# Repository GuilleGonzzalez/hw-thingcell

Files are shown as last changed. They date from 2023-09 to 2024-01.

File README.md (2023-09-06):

# ThingCell



## Description
'ThhingCell' is a device designed to control a other devices with a relay with MQTT over 4G .

Firmware used in this device is [fw-thingcell](https://github.com/GuilleGonzzalez/fw-thigcell), a custom made firmware implemented using [Arduino Home Assistant](https://github.com/dawidchyrzynski/arduino-home-assistant/tree/main) Arduino library ([docs](https://dawidchyrzynski.github.io/arduino-home-assistant/)).

## Power supply (WIP)

## Microprocessor (WIP)
Espressif [ESP8266](https://www.espressif.com/en/products/modules) module.

## Environmental sensing (WIP)
The board has enviromental sensors to measure temperature, humidity and atmospheric pressure:

### Temperature and humidity sensor
* Sensirion [SHT40](https://sensirion.com/products/catalog/SHT40).

### Pressure sensor
* Bosch [BMP581](https://www.bosch-sensortec.com/products/environmental-sensors/pressure-sensors/bmp581/).
  
## LEDs and buttons (WIP)

## Pin assignment (WIP)

| PIN | Func |
| --- | --- |
| GPIOx | F1 |

## Enclosure (WIP)
* Custom made in [Fusion 360](https://www.autodesk.es/products/fusion-360/overview).

# Changelog (WIP)
All notable changes to this project will be documented in this section.

The format is based on [Keep a Changelog](https://keepachangelog.com/en/1.0.0/)

## [unreleased] - 2023-09-06
Unreleased

[Unreleased]: https://github.com/GuilleGonzzalez/hw-thingcell

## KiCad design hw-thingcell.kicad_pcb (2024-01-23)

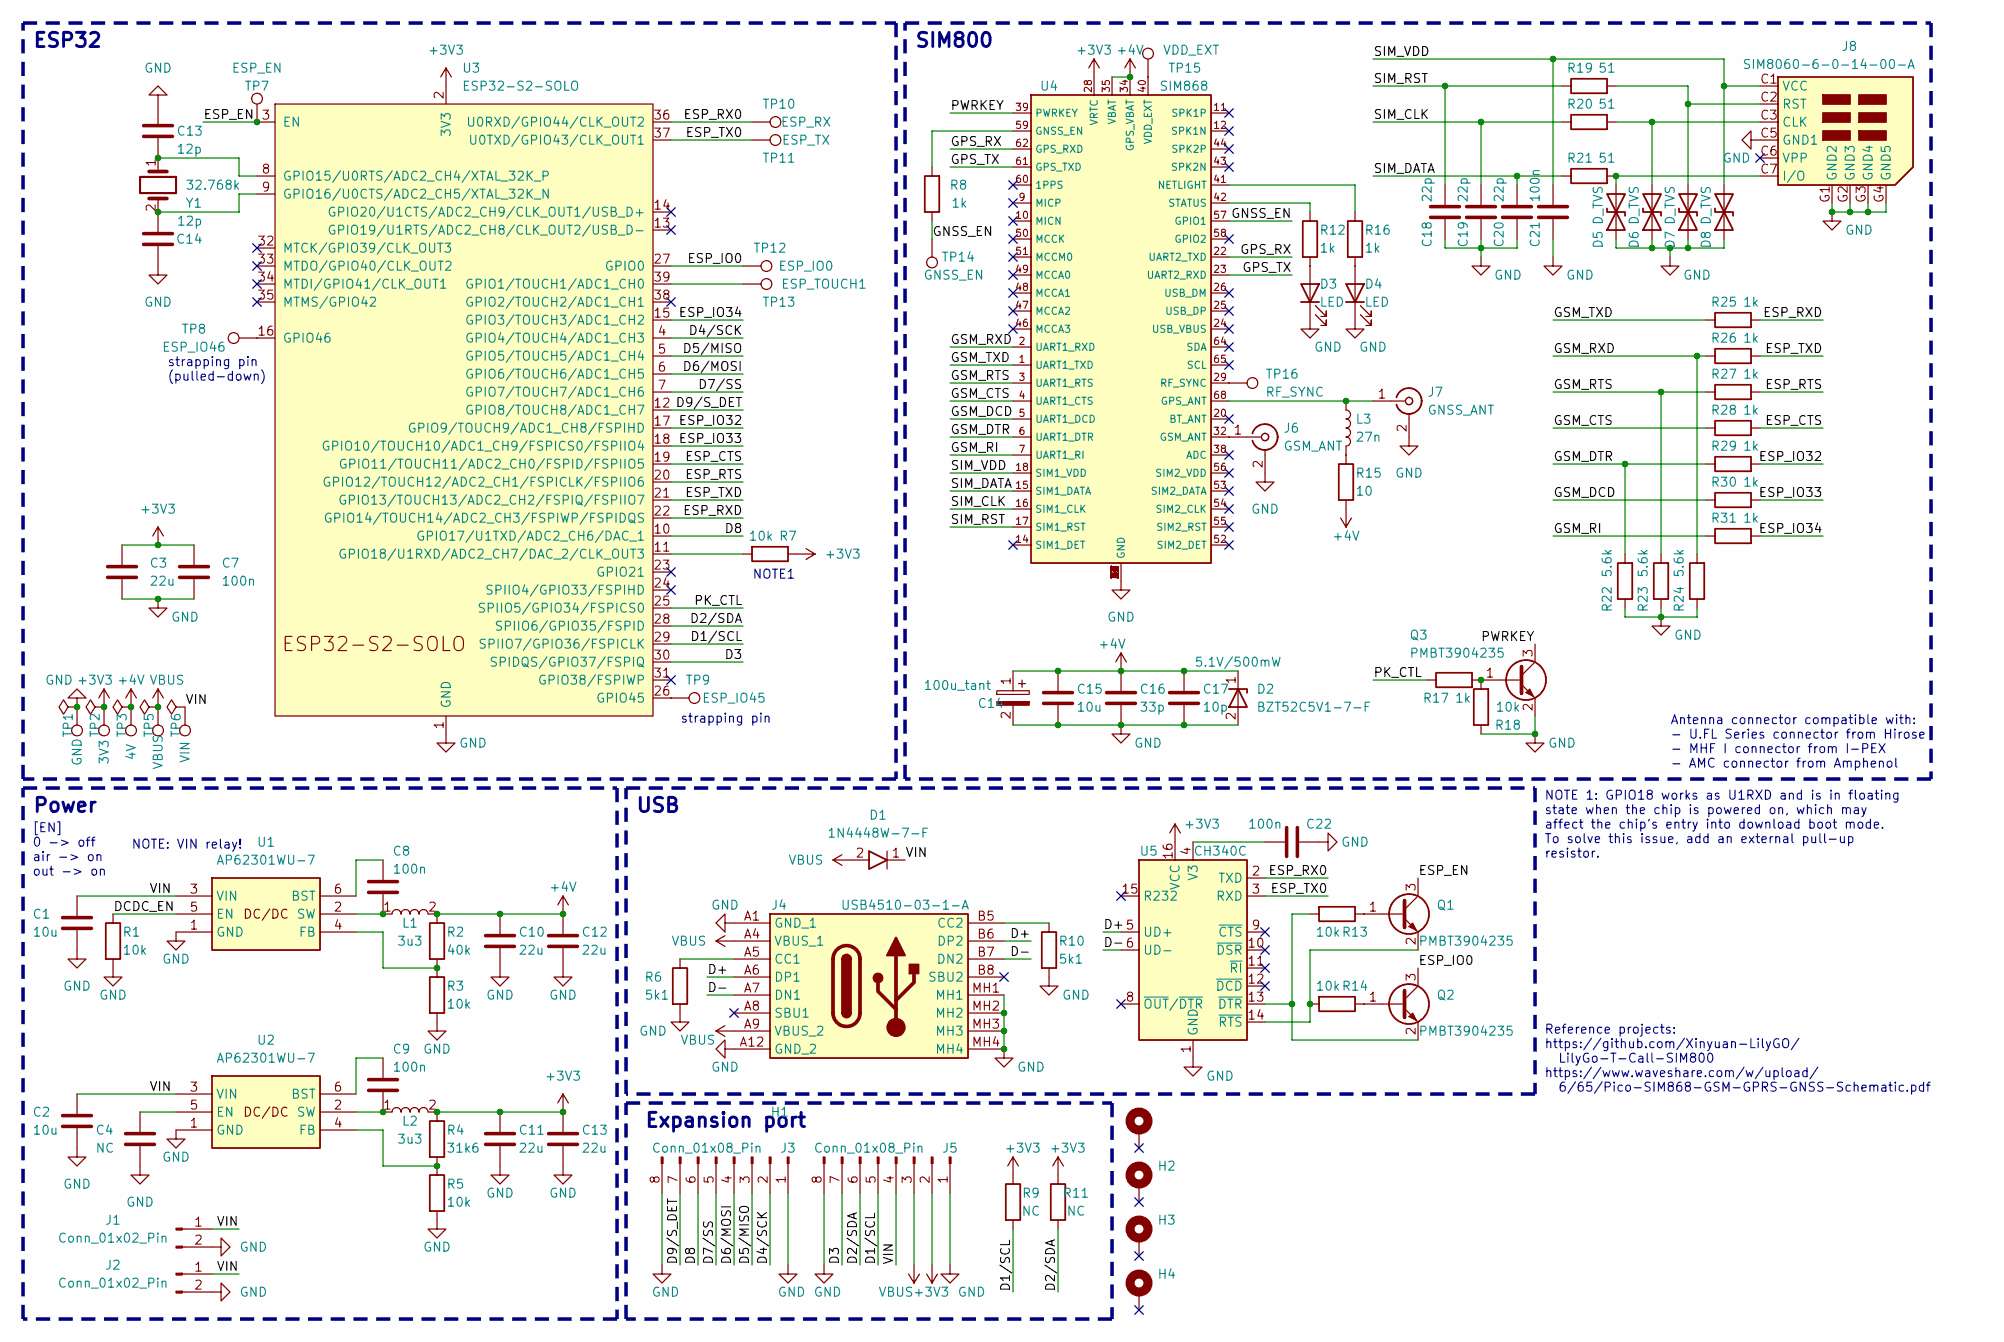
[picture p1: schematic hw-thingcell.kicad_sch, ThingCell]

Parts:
C1, C2, C15: 10u; C_0805_2012Metric
C3, C10, C11, C12, C13: 22u; C_0805_2012Metric
C4: NC; C_0402_1005Metric
C7, C8, C9, C21, C22: 100n; C_0402_1005Metric
C14: 100u_tant; CAPPM3528X210N; Manufacturer_Part_Number TPSB107K006R0250; Mouser Part Number 581-TPSB107K006R0250
C16: 33p; C_0402_1005Metric
C17: 10p; C_0402_1005Metric
C18, C19, C20: 22p; C_0402_1005Metric
D1: 1N4448W-7-F; D_SOD-123; Manufacturer_Part_Number 1N4448W-7-F; Mouser Part Number 621-1N4448W-F
D2: BZT52C5V1-7-F; SOD3716X145N; Manufacturer_Part_Number BZT52C5V1-7-F; Mouser Part Number 621-BZT52C5V1-F
D3, D4: LED; LED_0402_1005Metric
D5, D6, D7, D8: D_TVS; D_0402_1005Metric
H1, H2, H3, H4: MountingHole_Pad; MountingHole_2.2mm_M2_ISO7380_Pad
J1, J2: Conn_01x02_Pin; PinSocket_1x02_P2.54mm_Vertical
J3, J5: Conn_01x08_Pin; PinSocket_1x08_P2.54mm_Vertical
J4: USB4510-03-1-A; USB4510031A; Mouser Part Number 640-USB4510031A
J6: GSM_ANT; U.FL_CONNECTOR
J7: GNSS_ANT; U.FL_CONNECTOR
J8: SIM8060-6-0-14-00-A; SIM8060601400A; Manufacturer_Part_Number SIM8060-6-0-14-00-A; Mouser Part Number 640-SIM8060601400A
L1, L2: 3u3; SRN5020TA3R3M; Manufacturer_Part_Number SRN5020TA-3R3M; Mouser Part Number 652-SRN5020TA-3R3M
L3: 27n; L_0402_1005Metric
Q1, Q2, Q3: PMBT3904235; SOT-23; Manufacturer_PN PMBT3904,235
R1, R3, R5, R7, R13, R14, R18: 10k; R_0402_1005Metric
R2: 40k; R_0402_1005Metric
R4: 31k6; R_0402_1005Metric
R6, R10: 5k1; R_0402_1005Metric
R8, R12, R16, R17, R25, R26, R27, R28, R29, R30, R31: 1k; R_0402_1005Metric
R9, R11: NC; R_0402_1005Metric
R15: 10; R_0402_1005Metric
R19, R20, R21: 51; R_0402_1005Metric
R22, R23, R24: 5.6k; R_0402_1005Metric
TP1: GND; TestPoint_Pad_D1.0mm
TP2: 3V3; TestPoint_Pad_D1.0mm
TP3: 4V; TestPoint_Pad_D1.0mm
TP5: VBUS; TestPoint_Pad_D1.0mm
TP6: VIN; TestPoint_Pad_D1.0mm
TP7: ESP_EN; TestPoint_Pad_D1.0mm
TP8: ESP_IO46; TestPoint_Pad_D1.0mm
TP9: ESP_IO45; TestPoint_Pad_D1.0mm
TP10: ESP_RX; TestPoint_Pad_D1.0mm
TP11: ESP_TX; TestPoint_Pad_D1.0mm
TP12: ESP_IO0; TestPoint_Pad_D1.0mm
TP13: ESP_TOUCH1; TestPoint_Pad_D1.0mm
TP14: GNSS_EN; TestPoint_Pad_D1.0mm
TP15: VDD_EXT; TestPoint_Pad_D1.0mm
TP16: RF_SYNC; TestPoint_Pad_D1.0mm
U1, U2: AP62301WU-7; SOT95P280X100-6N; Manufacturer_Part_Number AP62301WU-7; Mouser Part Number 621-AP62301WU-7
U3: ESP32-S2-SOLO
U4: SIM868
U5: CH340C; SOIC-16_3.9x9.9mm_P1.27mm
Y1: 32.768k; SC32S7PF20PPM; Manufacturer_Part_Number SC32S-7PF20PPM; Mouser Part Number 628-SC32S-7PF20PPM

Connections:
/D1/SCL: J5.5, R9.2, U3.29 (SPIIO7/GPIO36/FSPICLK)
/D2/SDA: J5.6, R11.2, U3.28 (SPIIO6/GPIO35/FSPID)
/D3: J5.7, U3.30 (SPIDQS/GPIO37/FSPIQ)
/D4/SCK: J3.2, U3.4 (GPIO4/TOUCH4/ADC1_CH3)
/D5/MISO: J3.3, U3.5 (GPIO5/TOUCH5/ADC1_CH4)
/D6/MOSI: J3.4, U3.6 (GPIO6/TOUCH6/ADC1_CH5)
/D7/SS: J3.5, U3.7 (GPIO7/TOUCH7/ADC1_CH6)
/D8: J3.6, U3.10 (GPIO17/U1TXD/ADC2_CH6/DAC_1)
/D9/S_DET: J3.7, U3.12 (GPIO8/TOUCH8/ADC1_CH7)
/D+: J4.A6 (DP1), J4.B6 (DP2), U5.5 (UD+)
/D-: J4.A7 (DN1), J4.B7 (DN2), U5.6 (UD-)
/DCDC_EN: R1.1, U1.5 (EN)
/ESP_CTS: R28.2, U3.19 (GPIO11/TOUCH11/ADC2_CH0/FSPID/FSPIIO5)
/ESP_EN: Q1.3, TP7.1, U3.3 (EN)
/ESP_IO0: Q2.3, TP12.1, U3.27 (GPIO0)
/ESP_IO32: R29.2, U3.17 (GPIO9/TOUCH9/ADC1_CH8/FSPIHD)
/ESP_IO33: R30.2, U3.18 (GPIO10/TOUCH10/ADC1_CH9/FSPICS0/FSPIIO4)
/ESP_IO34: R31.2, U3.15 (GPIO3/TOUCH3/ADC1_CH2)
/ESP_RTS: R27.2, U3.20 (GPIO12/TOUCH12/ADC2_CH1/FSPICLK/FSPIIO6)
/ESP_RX0: TP10.1, U3.36 (U0RXD/GPIO44/CLK_OUT2), U5.2 (TXD)
/ESP_RXD: R25.2, U3.22 (GPIO14/TOUCH14/ADC2_CH3/FSPIWP/FSPIDQS)
/ESP_TX0: TP11.1, U3.37 (U0TXD/GPIO43/CLK_OUT1), U5.3 (RXD)
/ESP_TXD: R26.2, U3.21 (GPIO13/TOUCH13/ADC2_CH2/FSPIQ/FSPIIO7)
/GNSS_EN: R8.1, TP14.1, U4.57 (GPIO1)
/GPS_RX: U4.22 (UART2_TXD), U4.62 (GPS_RXD)
/GPS_TX: U4.23 (UART2_RXD), U4.61 (GPS_TXD)
/GSM_CTS: R28.1, U4.4 (UART1_CTS)
/GSM_DCD: R30.1, U4.5 (UART1_DCD)
/GSM_DTR: R22.2, R29.1, U4.6 (UART1_DTR)
/GSM_RI: R31.1, U4.7 (UART1_RI)
/GSM_RTS: R23.2, R27.1, U4.3 (UART1_RTS)
/GSM_RXD: R24.2, R26.1, U4.2 (UART1_RXD)
/GSM_TXD: R25.1, U4.1 (UART1_TXD)
/PK_CTL: R17.1, U3.25 (SPIIO5/GPIO34/FSPICS0)
/PWRKEY: Q3.3, U4.39 (PWRKEY)
/SIM_CLK: C19.1, R20.1, U4.16 (SIM1_CLK)
/SIM_DATA: C20.1, R21.1, U4.15 (SIM1_DATA)
/SIM_RST: C18.1, R19.1, U4.17 (SIM1_RST)
/SIM_VDD: C21.1, D8.2 (A2), J8.C1 (VCC), U4.18 (SIM1_VDD)
/VIN: C1.1, C2.1, D1.1, J1.1, J2.1, J5.4, TP6.1, U1.3 (VIN), U2.3 (VIN)
unnamed: D3.2 (A), R12.2
unnamed: D4.2 (A), R16.2
unnamed: D5.2 (A2), J8.C7 (I/O), R21.2
unnamed: D6.2 (A2), J8.C3 (CLK), R20.2
unnamed: D7.2 (A2), J8.C2 (RST), R19.2
unnamed: J4.A5 (CC1), R6.1
unnamed: J4.B5 (CC2), R10.1
unnamed: J6.1 (In), U4.32 (GSM_ANT)
unnamed: J7.1 (In), L3.1, U4.68 (GPS_ANT)
unnamed: L3.2, R15.1
unnamed: Q1.1, R13.1
unnamed: Q2.1, R14.1
unnamed: Q3.1, R17.2, R18.2
unnamed: C8.1, U1.6 (BST)
unnamed: R2.2, R3.1, U1.4 (FB)
unnamed: C8.2, L1.1, U1.2 (SW)
unnamed: C9.1, U2.6 (BST)
unnamed: C4.1, U2.5 (EN)
unnamed: R4.2, R5.1, U2.4 (FB)
unnamed: C9.2, L2.1, U2.2 (SW)
unnamed: TP13.1, U3.39 (GPIO1/TOUCH1/ADC1_CH0)
unnamed: R7.2, U3.11 (GPIO18/U1RXD/ADC2_CH7/DAC_2/CLK_OUT3)
unnamed: TP9.1, U3.26 (GPIO45)
unnamed: TP8.1, U3.16 (GPIO46)
unnamed: R8.2, U4.59 (GNSS_EN)
unnamed: R16.1, U4.41 (NETLIGHT)
unnamed: TP16.1, U4.29 (RF_SYNC)
unnamed: R12.1, U4.42 (STATUS)
unnamed: TP15.1, U4.40 (VDD_EXT)
unnamed: C22.1, U5.4 (V3)
unnamed: Q2.2, R13.2, U5.13 (~DTR)
unnamed: Q1.2, R14.2, U5.14 (~RTS)
VBUS: D1.2, J4.A4 (VBUS_1), J4.A9 (VBUS_2), J5.3, TP5.1

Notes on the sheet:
NOTE 1: GPIO18 works as U1RXD and is in floating state when the chip is powered on, which may affect the chip’s entry into download boot mode. To solve this issue, add an external pull-up resistor.
NOTE1
strapping pin (pulled-down)
strapping pin
Antenna connector compatible with: - U.FL Series connector from Hirose - MHF I connector from I-PEX - AMC connector from Amphenol
ESP32
[EN] 0 -> off air -> on out -> on
Reference projects: https://github.com/Xinyuan-LilyGO/ LilyGo-T-Call-SIM800 https://www.waveshare.com/w/upload/ 6/65/Pico-SIM868-GSM-GPRS-GNSS-Schematic.pdf
NOTE: VIN relay!
Expansion port
SIM800
Power
USB

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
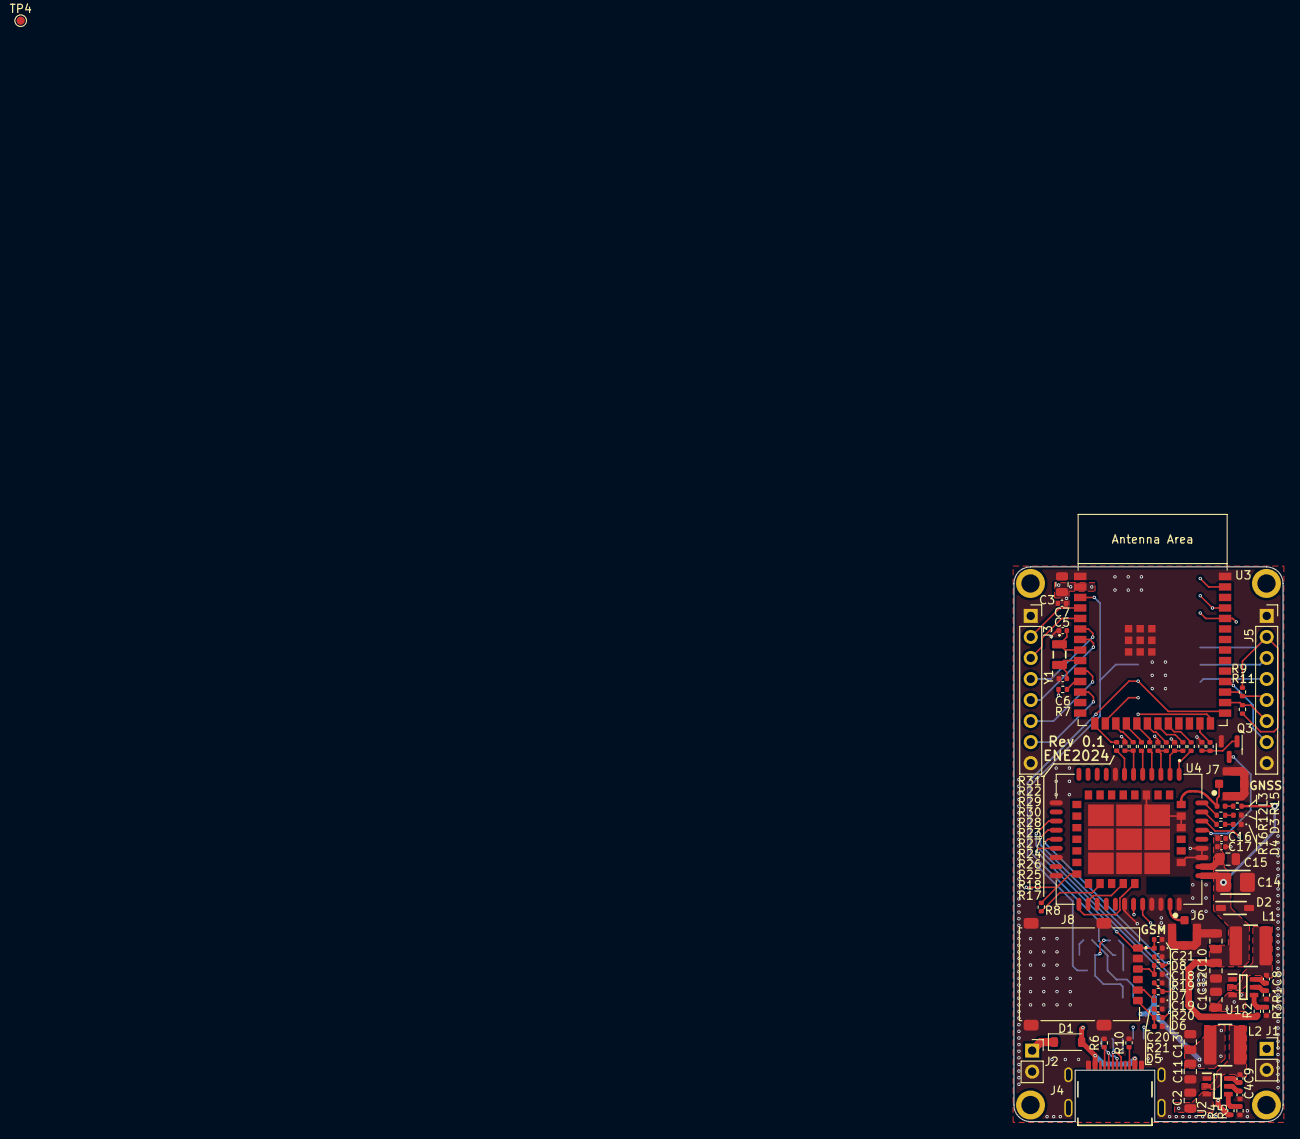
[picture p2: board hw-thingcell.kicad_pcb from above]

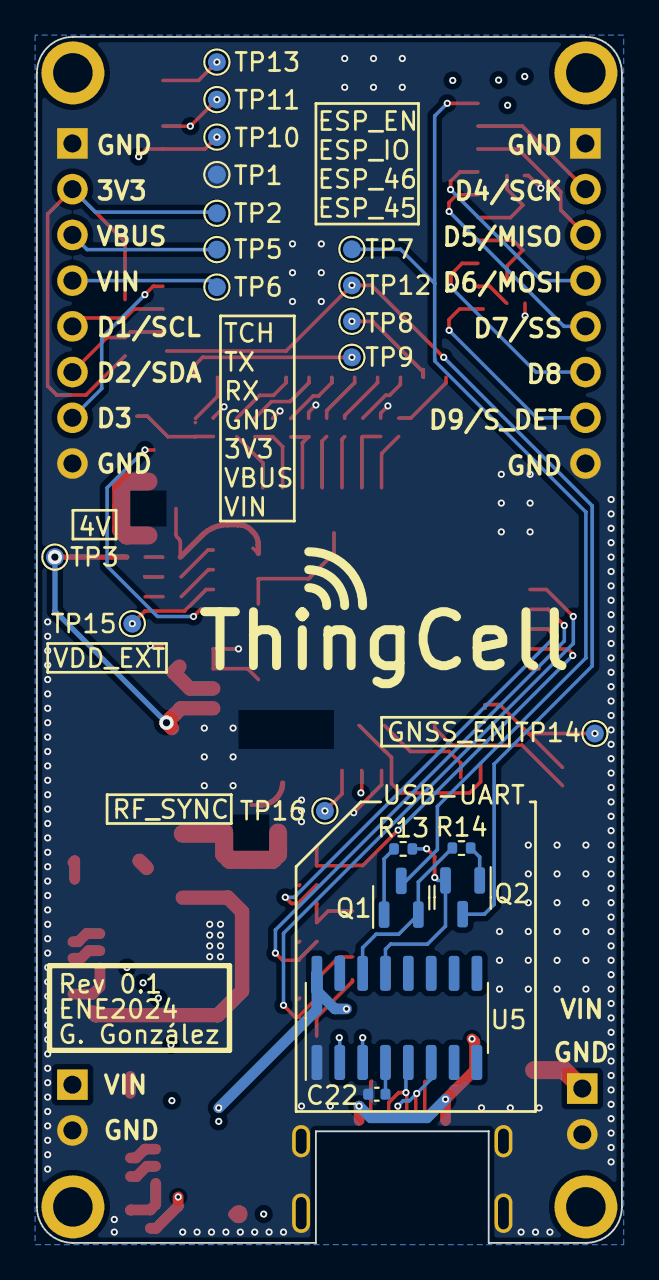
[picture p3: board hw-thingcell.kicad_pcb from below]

Board: 4 copper layers, 32.5 x 67.0 mm, 101 parts (21 on the bottom side), 78 nets.

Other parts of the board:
C5, C6: 12p; C_0402_1005Metric
TP4: 5V; TestPoint_Pad_D1.0mm

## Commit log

2023-09-06 Draft schematic
    [hw-thingcell.kicad_sch]
2023-09-15 Continue with schematic adding ESP and SIM components
    [hw-thingcell.kicad_sch]
2023-11-23 Work on schematic
    [hw-thingcell.kicad_sch]
2023-11-23 Replace SIM800C with SIM868
    [hw-thingcell.kicad_sch]
2023-11-24 Add antenna connector and passive components
    [hw-thingcell.kicad_sch]
2023-11-24 Add USB-UART and USB-C connector
    [hw-thingcell.kicad_sch]
2023-11-25 Change ESP-WROOM to SOLO and schematic relocation
    [hw-thingcell.kicad_sch]
2023-12-01 Add supply diode and match all symbols&footprints
    [hw-thingcell.kicad_sch]
2023-12-05 Sch reviewed
    [hw-thingcell.kicad_sch]
2023-12-05 First placement
    [hw-thingcell.kicad_pcb, hw-thingcell.kicad_sch]
2024-01-08 Routed all components
    [hw-thingcell.kicad_pcb, hw-thingcell.kicad_sch]
2024-01-08 Work in texts and graphics
    [hw-thingcell.kicad_pcb, hw-thingcell.kicad_sch]
2024-01-09 Add coplanar wave guides
    [hw-thingcell.kicad_pcb]
2024-01-23 Final revision
    [hw-thingcell.kicad_pcb, hw-thingcell.kicad_sch]
2024-01-23 Update Gerber export config
    [hw-thingcell.kicad_pcb]
